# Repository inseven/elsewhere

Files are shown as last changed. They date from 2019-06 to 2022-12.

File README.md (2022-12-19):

# Elsewhere



Livestream picture frame

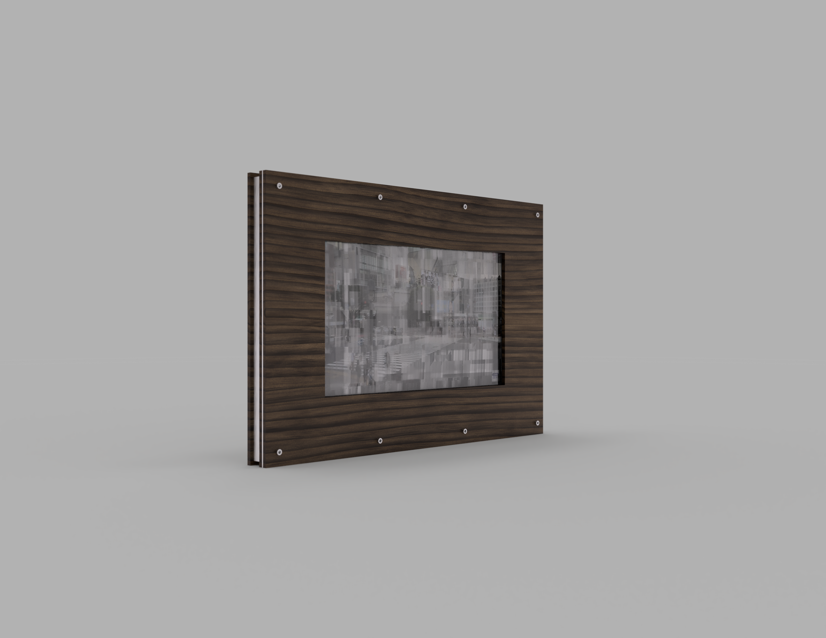
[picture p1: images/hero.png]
Render of the current Elsewhere design


## Parts

| **Part** | **Link** | Quantity | **Unit Price** | **Price** |
| --- | --- | --- | --- | --- |
| **Raspberry Pi Zero 2 W** | [Adafruit](https://www.adafruit.com/product/5291) | 1 | $15.00 | $15.00 |
| **Pimoroni HDMI 10" IPS LCD Screen Kit**  | [Adafruit](https://www.adafruit.com/product/4337) | 1 | $139.95 | $139.95 |
| HDMI Ribbon Cable, 30 cm | [Adafruit](https://www.adafruit.com/product/3562) | 1 | $2.75 | $2.75 |
| HDMI Plug Adapter | [Adafruit](https://www.adafruit.com/product/3548) | 1 | $6.50 | $6.50 |
| Mini HDMI Plug Adapter | [Adafruit](https://www.adafruit.com/product/3552) | 1 | $6.50 | $6.50 |
| **ATXRaspi R3** | [LowPowerLab](https://lowpowerlab.com/shop/product/91) | 1 | $17.95 | $17.95 |
| Jumper Wire | [LowPowerLab](https://lowpowerlab.com/shop/product/154) | 4 | $0.74 ($2.95 for 4) | $2.95 |
| D-Ring Picture Hanger, M4 | | 2 | | |
| USB-C Panel Mount | [eBay](https://www.ebay.com/itm/143134180140) | 1 | $6.29 | $6.29 |
| USB-C to Micro USB Adapter | [Amazon](https://www.amazon.com/gp/product/B07GH5KJH2/) | 1 | $6.99 | $6.99 |
| Micro USB Splitter Cable | [Amazon](https://www.amazon.com/gp/product/B017OPOG58/) | 1 | $6.79 | $6.79 |
| microSD Card, 32GB | [Amazon](https://www.amazon.com/SAMSUNG-Select-microSDXC-Adapter-MB-ME128HA/dp/B06XWN9Q99) | 1 | $7.99 | $7.99 |
| Female to Female Dupont Wire, 30cm | [Amazon](https://www.amazon.com/dp/B07GD1W1VL) | 6 | $0.08 ($8.99 for 120) | $0.48 |
| M3 Standoff, 10mm | [McMaster-Carr](https://www.mcmaster.com/94868A166/) | 8 | $1.24 | $9.92 |
| 4-40 Socket Head Screw, Low-Profile, 1/4" | [McMaster-Carr](https://www.mcmaster.com/93615A110/) | 2 | $1.55 (Pack of 10) | $3.10 |
| M3 Socket Head Screw, Low-Profile, 12mm | [McMaster-Carr](https://www.mcmaster.com/92855A313/) | 8 | $0.11 (Pack of 25) | $0.22 |
| M3 Socket Head Screw, Low-Profile, 6mm | [McMaster-Carr](https://www.mcmaster.com/92855A307/) | 8 | $0.30 (Pack of 25) | $0.60 |
| M2.5 Socket Head Screw, 6mm | [McMaster-Carr](https://www.mcmaster.com/91292A010/) | 18 | $0.06 ($6.00 for 100) | $1.08 |
| M2.5 Socket Head Screw, 4mm | [McMaster-Carr](https://www.mcmaster.com/91292A015/) | 18 | $0.30 ($7.43 for 25) | $5.40 |
| M2.5 Socket Head Screw, 10mm | [McMaster-Carr](https://www.mcmaster.com/91292A014/) | 2 | $0.07 ($6.54 for 100) | $0.14 |
| M2.5 Nut | [McMaster-Carr](https://www.mcmaster.com/91828A113/) | 2 | $0.08 ($7.18 for 100) | $0.16 |
| M2.5 Washer, 0.5mm | [McMaster-Carr](https://www.mcmaster.com/98689A111/) | 6 | $0.03 ($2.57 for 100) | $0.18 |
| M4 Socket Head Screw, Low-Profile, Partially Threaded, 10mm | [McMaster-Carr](https://www.mcmaster.com/96970A111/) | 2 | $1.48 | $2.96 |
| M4 Washer, 0.8mm | [McMaster-Carr](https://www.mcmaster.com/93475A230/) | 2 | $0.04 ($3.14 for 100) | $0.08 |
| M4 Locknut | [McMaster-Carr](https://www.mcmaster.com/93625A150/) | 2 | $0.08 ($7.67 for 100) | $0.16 |
| M2.5 Standoff, 6mm | [Digi-Key](https://www.digikey.com/en/products/detail/970060154/732-12827-ND/9488531) | 18 | $0.34 ($16.95 for 50) | $6.12 |
| **Laser-Cut Parts** | [Ponoko](https://ponoko.com) |  |  | $118.99 |
| **Controller Board** | [Oshpark](https://oshpark.com/shared_projects/Cnb1DUgJ) | 1 | $3.49 ($10.45 for 3) | $3.49 |
| Micro SD to Micro SD Extension Cable, 25cm | [AliExpress](https://www.aliexpress.com/item/4001154489373.html) | 1 | $3.00 | $3.00 |
| | | | | **$375.74** |

## Wiring

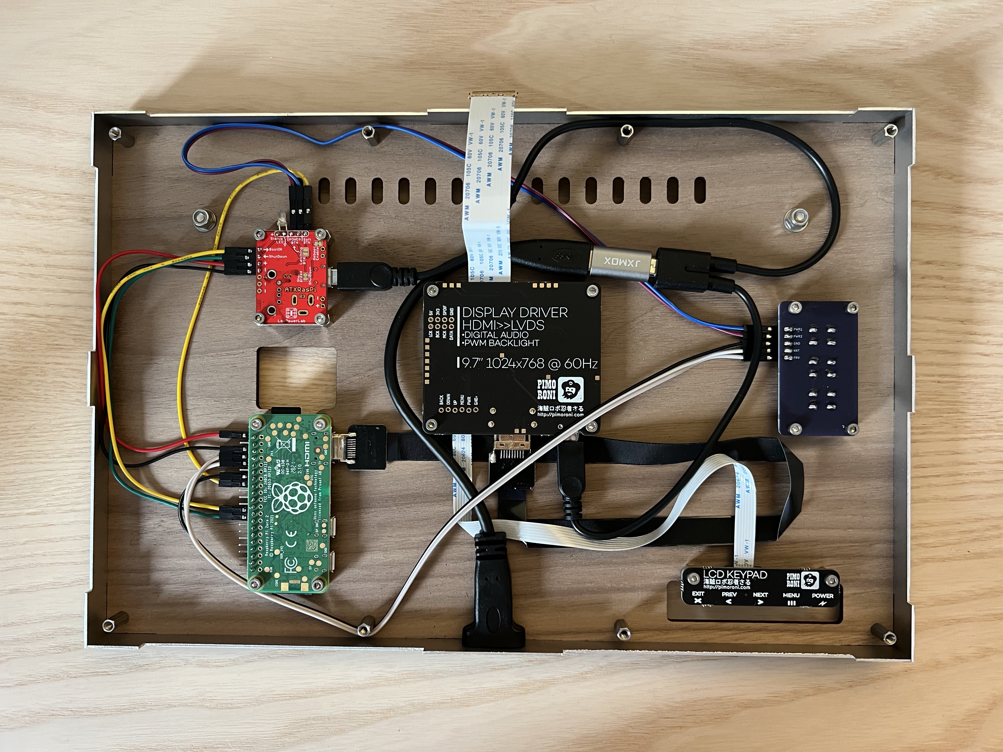
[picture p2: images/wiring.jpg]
Photograph of a recent version of Elsewhere showing the internal wiring


## Software Installation

1. Install Raspberry Pi OS Lite (Bullseye).

2. Add the package repository to `/etc/apt/sources.list`:

   ```bash
   deb [trusted=yes] http://packages.inseven.co.uk/raspbian/ ./
   ```

3. Update the `dtoverlay` property in `/boot/config.txt` to:

   ```ini
   dtoverlay=vc4-fkms-v3d
   ```

   (See https://forums.raspberrypi.com/viewtopic.php?t=324835.)
   
4. Add `fbcon=map:2 disable_splash=1 ` to `/boot/cmdline.txt`.

   These changes are as follows:

   - `fbcon=map:2` – Redirects the console during boot to ensure it doesn't appear on the HDMI display.
   - `disable_splash=1` – Disable the boot splash screen.

5. Disable the Serial Port and SPI:

   ```bash
   sudo raspi-config
   ```

   - Disable Serial Port
     - Interface Options
     - Serial Port
     - Login Shell: No
     - Serial Port Hardware: No
   - Disable SPI
     - Interface Options
     - SPI
     - Enabled: No

6. Reboot:

   ```bash
   sudo reboot
   ```

7. Update and upgrade Raspbian, and install Elsewhere:

   ```bash
   sudo apt update
   sudo apt upgrade --yes
   sudo apt install elsewhere --yes
   ```

8. Assuming everything has gone to plan, Elsewhere should now be running.

#### Unattended Upgrades

1. Enable all [unattended upgrades](https://wiki.debian.org/UnattendedUpgrades) by uncommenting the following lines in `/etc/apt/apt.conf.d/50unattended-upgrades`:

   ```
   Unattended-Upgrade::Origins-Pattern {
           // ...
           "origin=Debian,codename=${distro_codename}-updates";
           "origin=Debian,codename=${distro_codename}-proposed-updates";
           // ..
   }
   ```

2. Reboot:

   ```bash
   sudo reboot
   ```

## Troubleshooting

### Device takes too long to shutdown and ATXRaspi doesn't cut power

- Re-enable the console by removing `fbcon=map:2` from `/boot/cmdline.txt`.
- Check the the shutdown logs; are any services taking a long time to stop?

### Tailscale doesn't takes too long to stop

Customise the Tailscale service to shorten the shutdown timeout:

- Override the service:

  ```bash
  sudo systemctl edit tailscaled.service
  ```

- Add the following section:

  ```
  [Service]
  TimeoutSec=5
  ```

## Builds

Elsewhere is an iterative project, meaning I've put together a number of prototypes along the way. The most recent one still has the 4:3 aspect ratio, and has been happily showing us views from the ISS for the last few months.

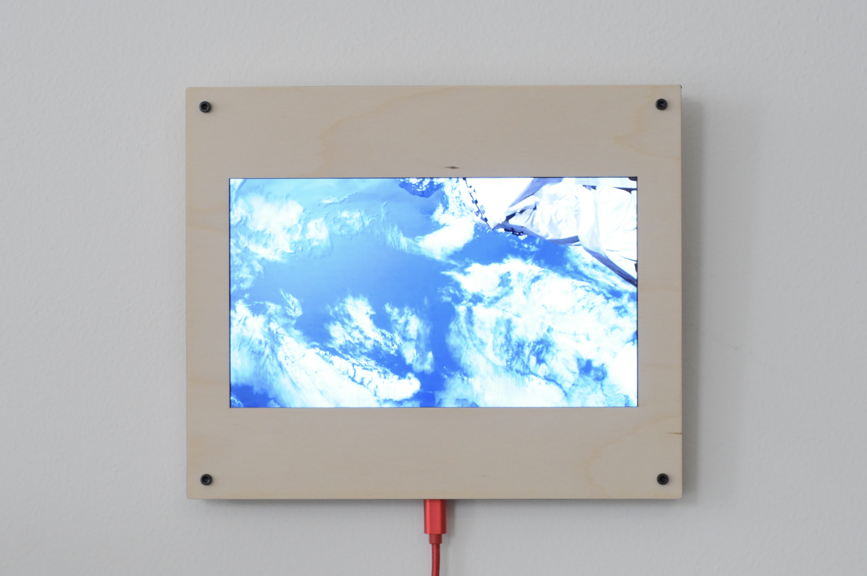
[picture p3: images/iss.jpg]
Elsewhere showing a livestream of Earth from the ISS


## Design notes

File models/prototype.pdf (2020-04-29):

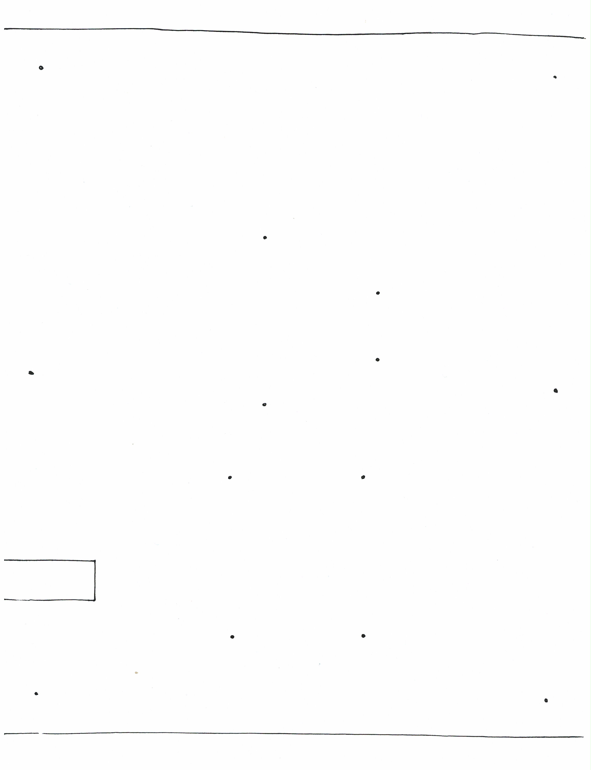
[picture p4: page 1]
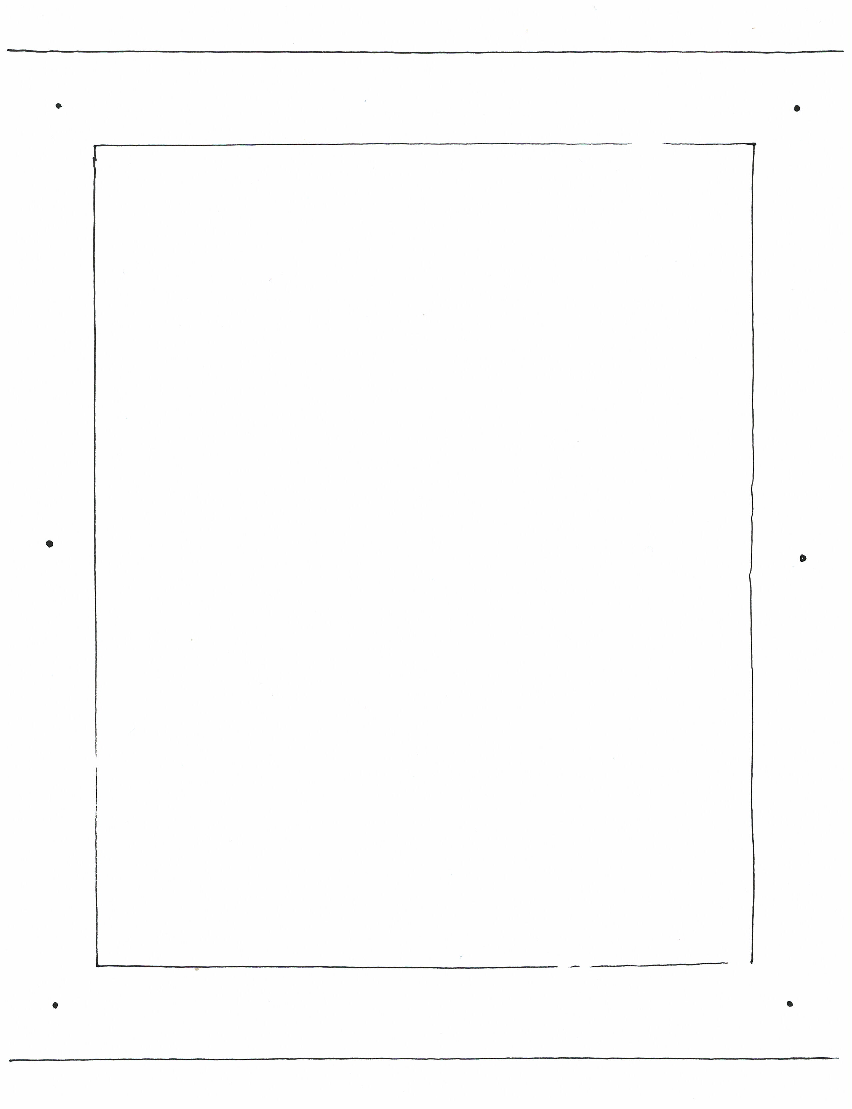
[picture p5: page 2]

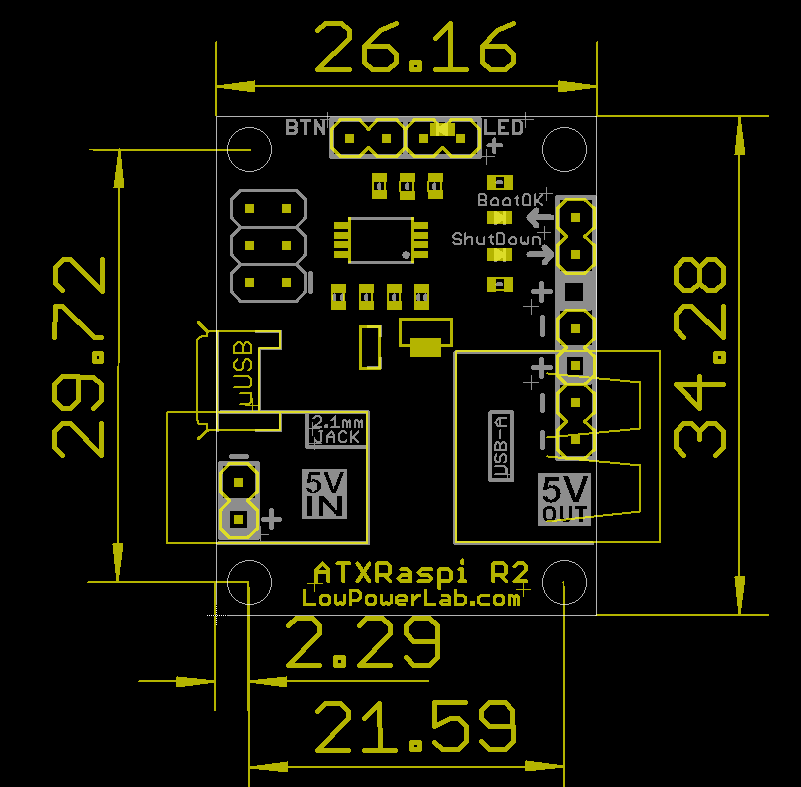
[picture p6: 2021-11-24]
schematics/ATXRaspi_R2_Outline_dimensions.png

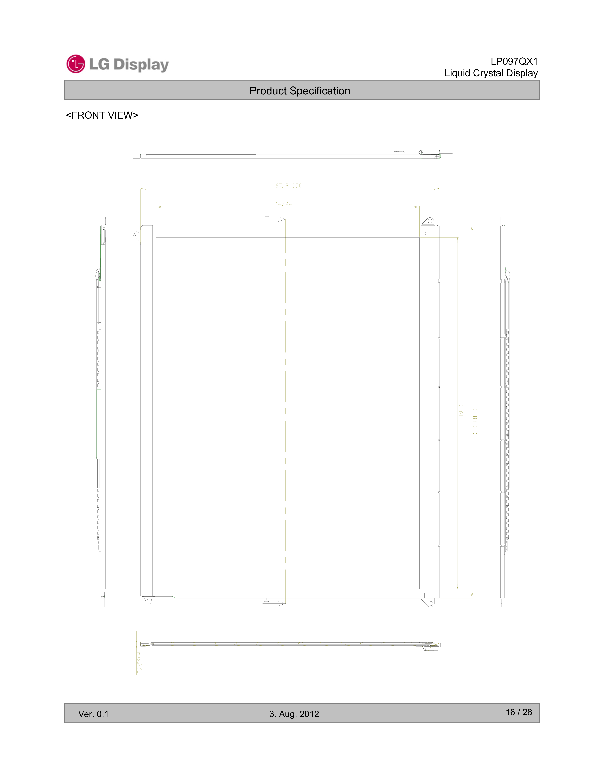
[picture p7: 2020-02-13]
schematics/LP097QX1-SPC1/front.png

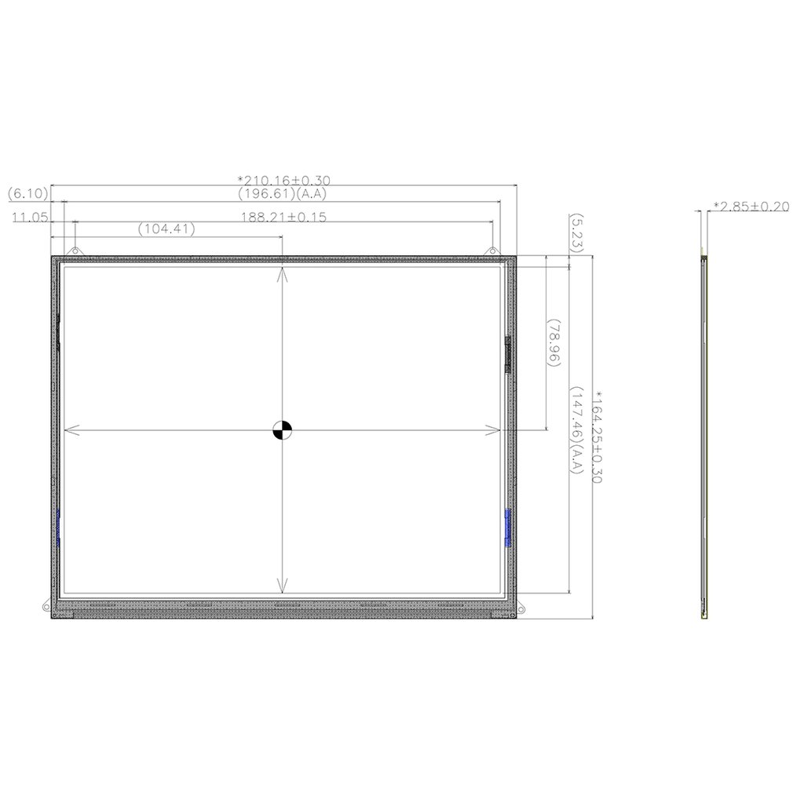
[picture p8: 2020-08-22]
schematics/10-inch-display-drawing_1024x1024.jpg

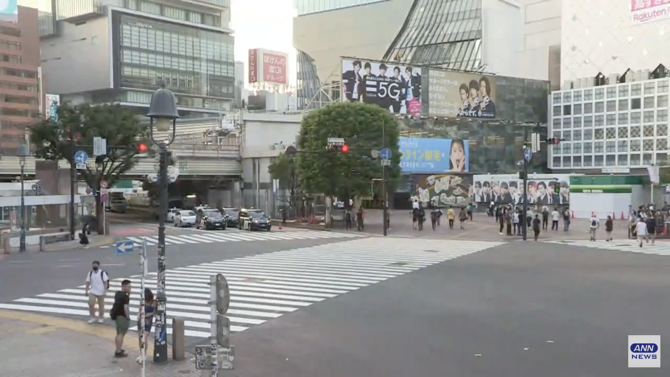
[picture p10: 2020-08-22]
models/placeholder.png

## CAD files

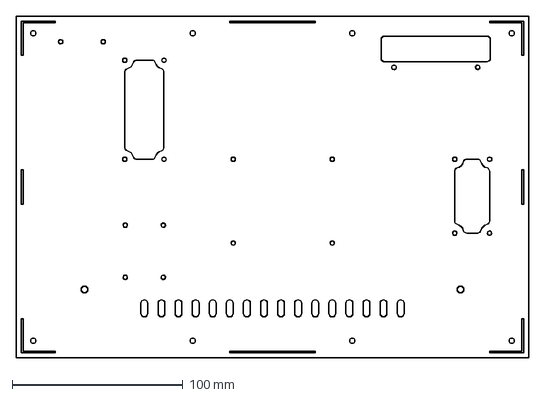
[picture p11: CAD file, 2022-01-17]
manufacture/v6/back.dxf
300.0 x 200.0 mm

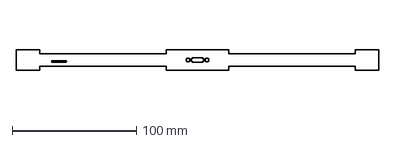
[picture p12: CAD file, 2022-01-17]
manufacture/v6/side-bottom.dxf
292.0 x 16.6 mm

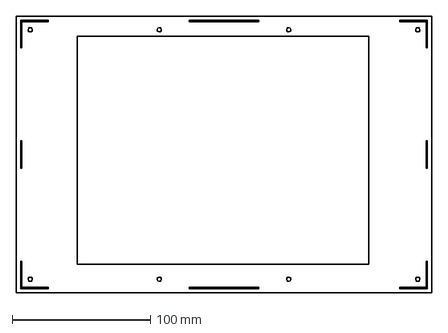
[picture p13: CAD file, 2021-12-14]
manufacture/v6/middle.dxf
300.0 x 200.0 mm

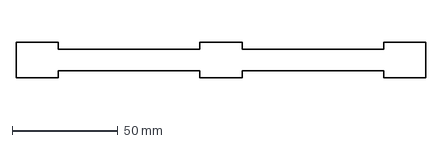
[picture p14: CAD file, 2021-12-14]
manufacture/v6/side-left.dxf
194.0 x 16.6 mm

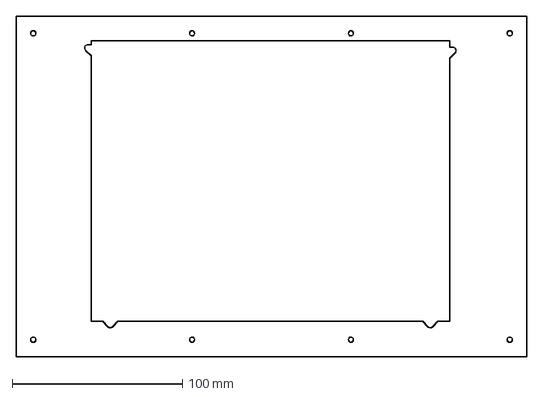
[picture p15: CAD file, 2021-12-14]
manufacture/v6/separator.dxf
300.0 x 200.0 mm

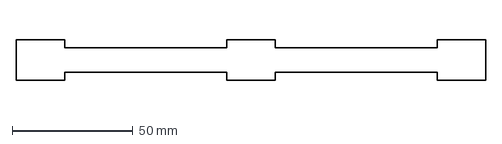
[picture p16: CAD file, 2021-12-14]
manufacture/v6/side-right.dxf
194.0 x 16.6 mm

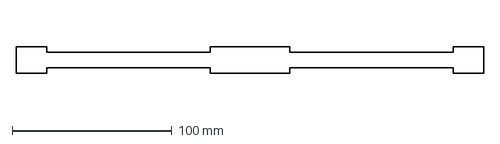
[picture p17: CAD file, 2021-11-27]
manufacture/v6/side-top.dxf
292.0 x 16.6 mm

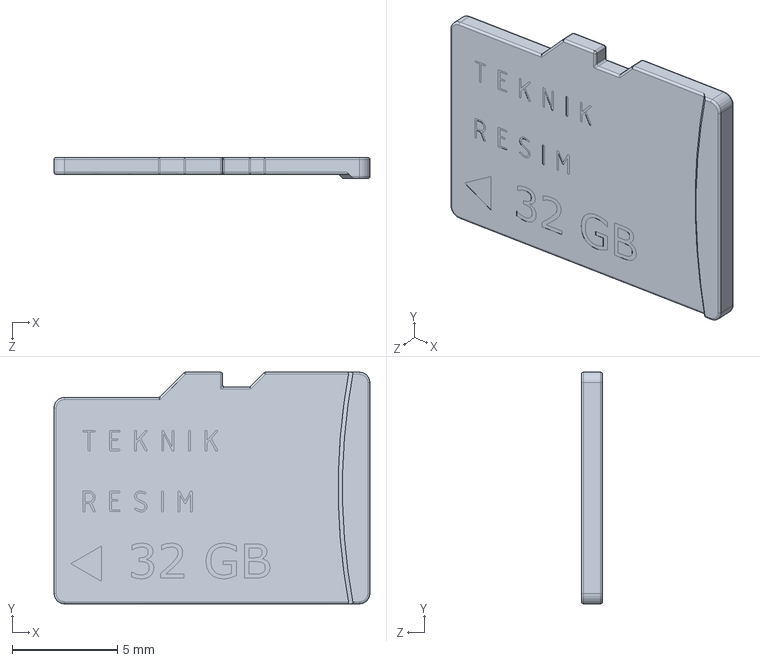
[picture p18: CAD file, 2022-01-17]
models/Micro SD Card.SLDPRT
15.0 x 11.0 x 1.00 mm

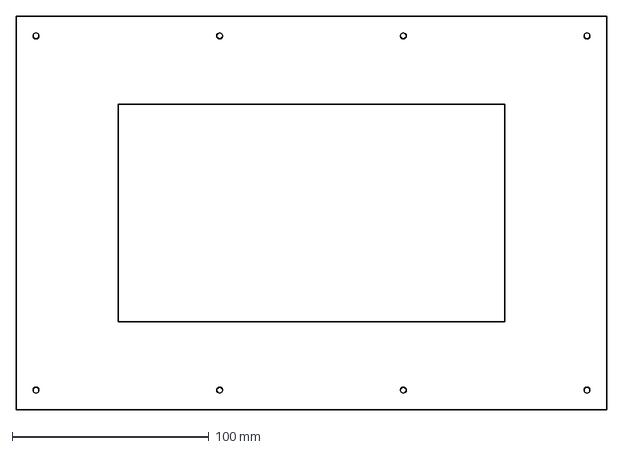
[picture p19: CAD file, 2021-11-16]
manufacture/v6/front.dxf
300.0 x 200.0 mm

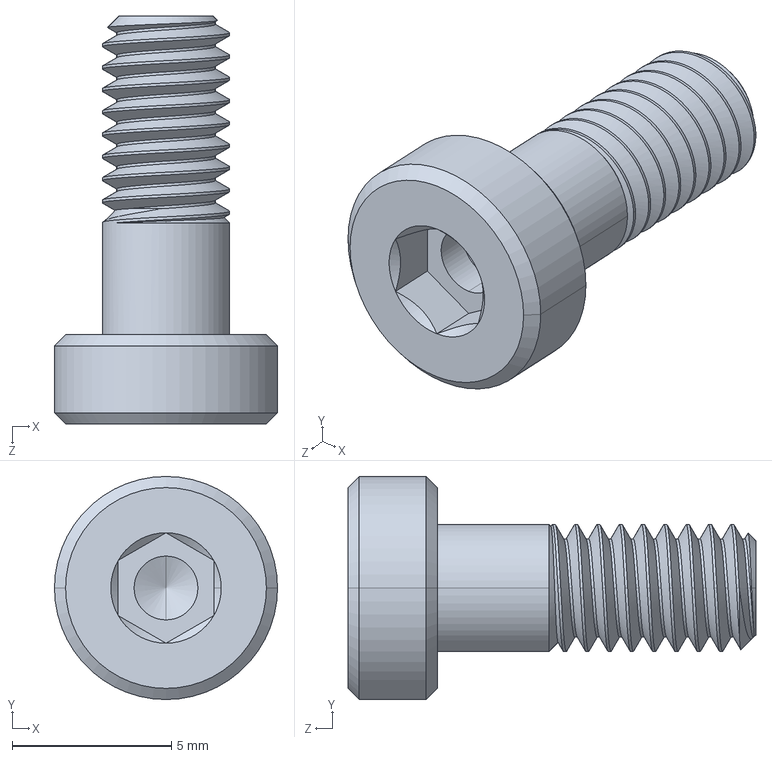
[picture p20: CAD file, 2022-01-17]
models/96970A111_18-8 Stainless Steel Low-Profile Socket Head Screw.STEP
7.00 x 7.00 x 12.8 mm

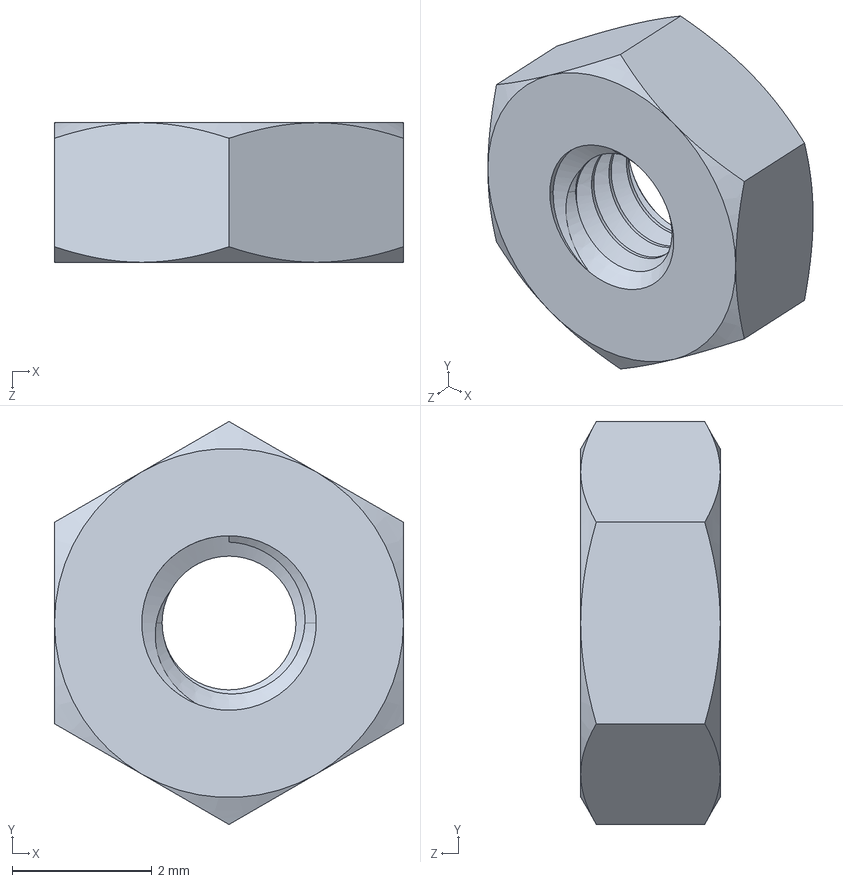
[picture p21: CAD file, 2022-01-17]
models/91828A113_18-8 Stainless Steel Hex Nut.STEP
5.00 x 5.77 x 2.00 mm

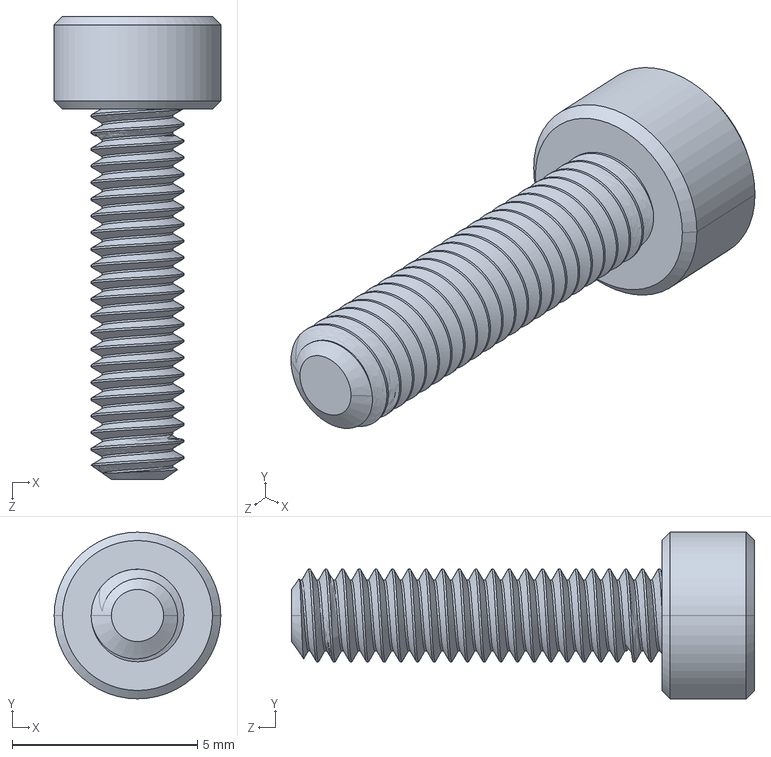
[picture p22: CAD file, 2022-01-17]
models/91292A014_18-8 Stainless Steel Socket Head Screw.STEP
4.50 x 4.50 x 12.5 mm

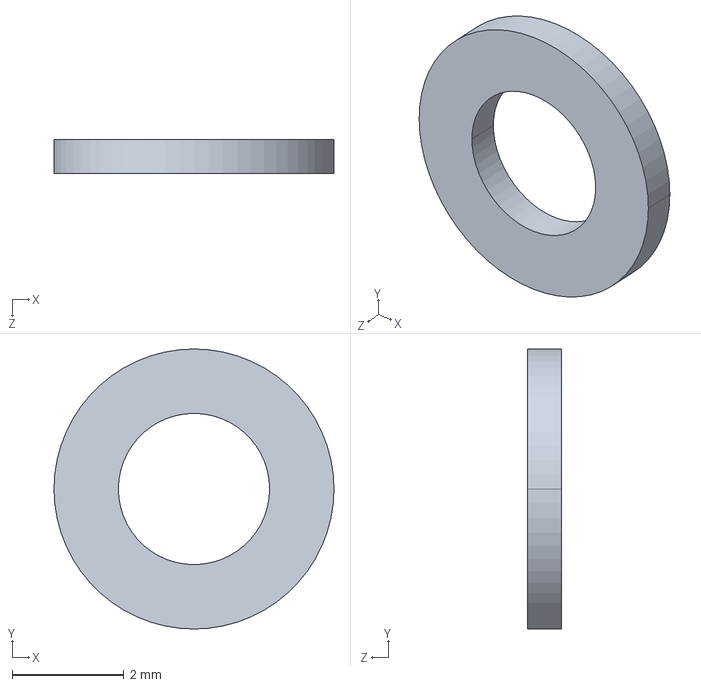
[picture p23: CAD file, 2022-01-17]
models/98689A111_General Purpose 18-8 Stainless Steel Washer.STEP
5.00 x 5.00 x 0.6 mm

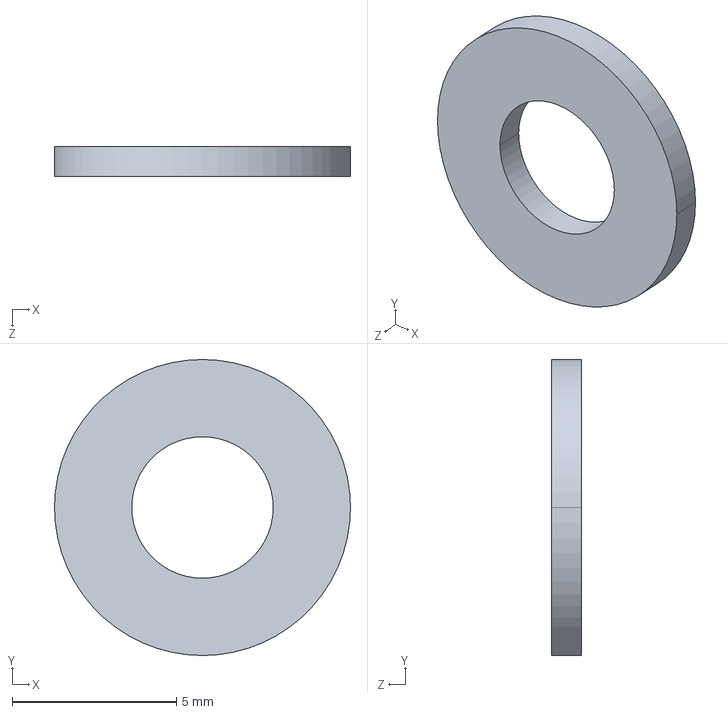
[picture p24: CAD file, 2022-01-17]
models/93475A230_18-8 Stainless Steel Washer.STEP
9.00 x 9.00 x 0.9 mm

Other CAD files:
models/93625A150_18-8 Stainless Steel Nylon-Insert Locknut.STEP
models/91292A010_18-8 Stainless Steel Socket Head Screw.SLDPRT
models/93615A110_18-8 Stainless Steel Low-Profile Socket Head Screw.SLDPRT
manufacture/v1/front.dxf
manufacture/v1/back.dxf
manufacture/v1/border.dxf
manufacture/v2/back.dxf
manufacture/v2/front.dxf
manufacture/v2/middle.dxf
manufacture/v2/separator.dxf
manufacture/v2/side-bottom.dxf
manufacture/v2/side-left.dxf
manufacture/v2/side-right.dxf
manufacture/v2/side-top.dxf
manufacture/v3/back.dxf
manufacture/v3/middle.dxf
manufacture/v3/side-bottom.dxf
manufacture/v3/side-left.dxf
manufacture/v3/side-right.dxf
manufacture/v3/side-top.dxf
manufacture/v4/back.dxf
manufacture/v4/middle.dxf
manufacture/v4/separator.dxf
manufacture/v4/side-bottom.dxf
manufacture/v4/side-left.dxf
manufacture/v4/side-right.dxf
models/PiZero.f3d

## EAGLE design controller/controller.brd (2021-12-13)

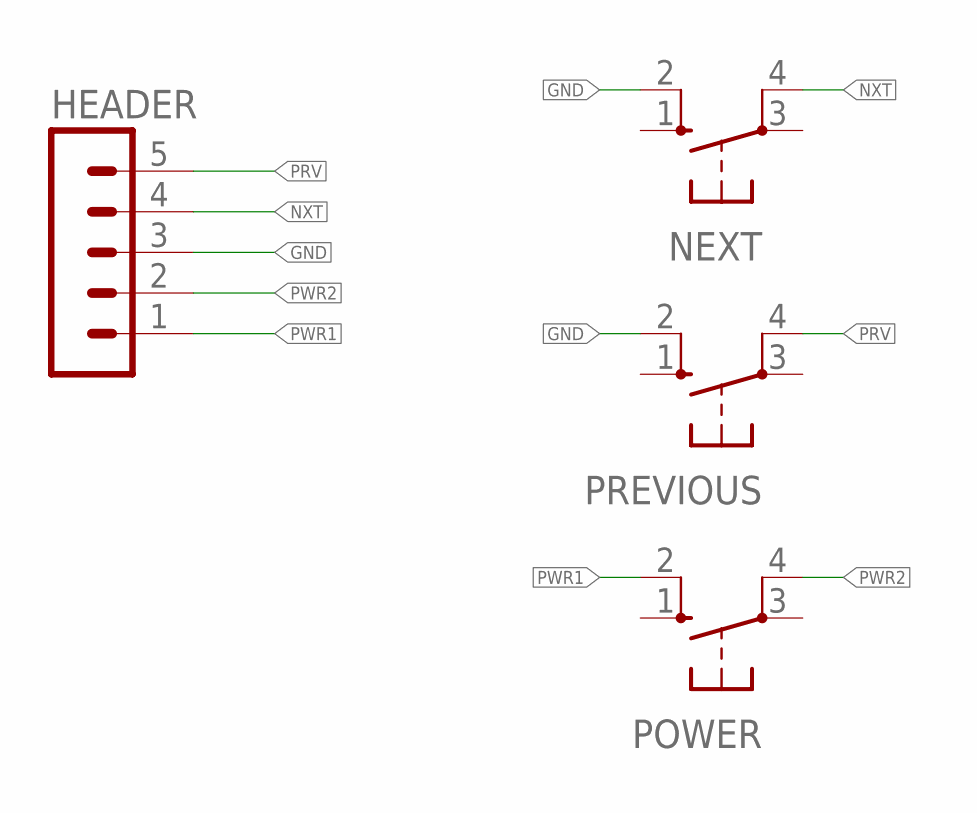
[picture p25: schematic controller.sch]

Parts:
HEADER: MA05-1
NEXT: 10-XX; B3F-10XX
POWER: 10-XX; B3F-10XX
PREVIOUS: 10-XX; B3F-10XX

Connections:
GND: HEADER.3, NEXT.2 (S1), PREVIOUS.2 (S1)
NXT: HEADER.4, NEXT.4 (P1)
PRV: HEADER.5, PREVIOUS.4 (P1)
PWR1: HEADER.1, POWER.2 (S1)
PWR2: HEADER.2, POWER.4 (P1)

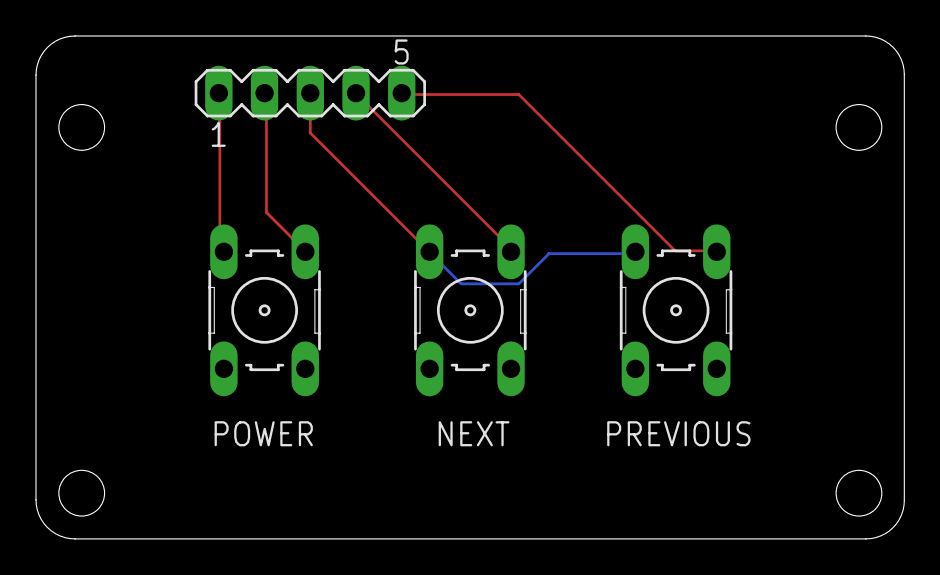
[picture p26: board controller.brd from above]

Board: 2 copper layers, 48.2 x 27.9 mm, 4 parts (0 on the bottom side), 5 nets.

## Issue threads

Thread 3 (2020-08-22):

Add vents to the rear of the device

jbmorley, 2020-08-22:

jbmorley, 2020-09-15:
Fixed.

Closed 2020-09-15.

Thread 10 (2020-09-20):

Add a cutout to make it easy to manipulate the display ribbon cable

jbmorley, 2020-09-20:
Adding a cutout to the rear of the case to make it easier to manipulate the ribbon cable once the display controller board is fixed in place should make assembly much easier.

jbmorley, 2021-11-13:
This doesn't actually seem necessary at this point.

Closed 2021-11-13.

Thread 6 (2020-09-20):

Increase the USB-C port aperture

jbmorley, 2020-09-20:
The hole for the USB port isn't quite large enough and needs a little more clearance.

jbmorley, 2021-11-13:
Done.

Closed 2021-11-13.

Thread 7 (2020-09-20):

Add a cutout for the Raspberry Pi SD card

jbmorley, 2020-09-20:
It'd be great to be able to get access to the SD card with the case fully assembled.

jbmorley, 2021-11-13:
Done.

Closed 2021-11-13.

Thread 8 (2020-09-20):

Consider making the case aspect ratio match the screen aspect ratio

jbmorley, 2020-09-20:
I think this would make it more visually balanced.

jbmorley, 2021-11-13:
16:9 didn't feel quite right, but 4:3 seems to work pretty well.

Closed 2021-11-13.

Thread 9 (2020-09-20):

Flip the Raspberry Pi over in the design

jbmorley, 2020-09-20:
Turning the Raspberry Pi over so the chips face outwards will make the SD card face the rear opening and make it much easier to access. It will also mean that the processor (and any heat sync) are fully exposed to the outside of the case which should help keep the temperature down.

jbmorley, 2021-11-13:
Done.

Closed 2021-11-13.

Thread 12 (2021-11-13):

Double check there's sufficient clearance for the display

jbmorley, 2021-11-13:
It looks like the screen may be bowing a little in the current implementation.

jbmorley, 2021-11-13:
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

jbmorley, 2021-11-13:
👌🏻

Closed 2021-11-13.

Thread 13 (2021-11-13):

Order parts for the updated devices

jbmorley, 2021-11-13:
- [x] 8 x 10mm standoffs
- [x] 8 x 12mm M3 hex bolts
- [x] 8 x 6mm M3 hex bolts
- [x] M2.5 bolts for the PCB mounting
- [x] M2.5 standoffs for the PCB mounting
- [x] 2 x M4 bolts for the picture frame hooks
- [x] 2 x M4 nuts for the picture frame hooks (locking nuts?)
- [x] 2 x M4 washers for the picture frame hooks

jbmorley, 2021-11-13:
Don't forget the M2.5 mountings for the PCBs.

jbmorley, 2021-11-13:
Bolts for mounting the picture frame hangers.

jbmorley, 2021-11-14:
- Second display (https://www.adafruit.com/product/4337)
- HDMI cables
- USB-C cable

jbmorley, 2021-11-26:
- [ ] Wood oil
- [ ] Sandpaper

jbmorley, 2021-12-27:
Done.

Closed 2021-12-27.

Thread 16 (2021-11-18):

Consider adding reinforcing bolts on the left and right sides

jbmorley, 2021-11-18:

jbmorley, 2021-11-26:
Closing as won't fix; we can re-raise this if there are actually issues.

Closed 2021-11-26.

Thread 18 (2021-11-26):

Custom PCB for controlling the device and display

jbmorley, 2021-11-26:
it would be great to be able to unify the display control board and the device controls (power, channel switching, etc) with a common control board which is designed with right-angle switches that can be pressed from the side of the device.

jbmorley, 2021-11-26:
Since this doesn't actually need to do anything more complex than provide a common mounting point for the switches, it might be possible to use some breadboard.

jbmorley, 2021-12-27:
Done.

Closed 2021-12-27.

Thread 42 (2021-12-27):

Create an Ansible script to set up a new Raspberry Pi

jbmorley, 2021-12-27:

jbmorley, 2021-12-31:
Closing as won't fix.

Closed 2021-12-31.

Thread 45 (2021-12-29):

Stop showing the version when the device has booted

jbmorley, 2021-12-29:

jbmorley, 2022-01-02:
I've made this change, but now it doesn't appear to be showing the splash at all.

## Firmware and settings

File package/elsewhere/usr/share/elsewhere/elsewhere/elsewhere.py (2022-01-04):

#!/usr/bin/env python3

# Copyright (c) 2018-2021 Jason Morley
#
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
import argparse
import atexit
import logging
import os
import re
import signal
import subprocess
import sys
import tempfile
import threading
import time
import urllib.request

import RPi.GPIO as GPIO
import gpiozero
import requests

from flask import Flask, escape, request, jsonify, send_from_directory

ROOT_DIRECTORY = os.path.dirname(os.path.abspath(__file__))
ELSEWHERE_DIRECTORY = "/usr/share/elsewhere"
SPLASH_DIRECTORY = os.path.join(ELSEWHERE_DIRECTORY, "splash")
IMAGES_DIRECTORY = os.path.join(SPLASH_DIRECTORY, "images")
SPLASH_IMAGE_PATH = os.path.join(IMAGES_DIRECTORY, "elsewhere.png")
SHUTTING_DOWN_IMAGE_PATH = os.path.join(IMAGES_DIRECTORY, "shutting-down.png")
FIM_SCRIPT_PATH = os.path.join(SPLASH_DIRECTORY, "script.txt")
FONT_PATH = os.path.join(ELSEWHERE_DIRECTORY, "fonts/Inter/static/Inter-Thin.ttf")

logging.basicConfig(level=logging.INFO, format="[%(asctime)s] [%(process)d] [%(levelname)s] %(message)s", datefmt='%Y-%m-%d %H:%M:%S %z')


def livestreamer(url):
    return subprocess.Popen(["streamlink", "--player", "cvlc --fullscreen --no-video-title-show", url, "best"])


app = Flask(__name__)


@app.after_request
def add_header(r):
    """
    Add headers to both force latest IE rendering engine or Chrome Frame,
    and also to cache the rendered page for 10 minutes.
    """
    r.headers["Cache-Control"] = "no-cache, no-store, must-revalidate"
    r.headers["Pragma"] = "no-cache"
    r.headers["Expires"] = "0"
    r.headers['Cache-Control'] = 'public, max-age=0'
    return r


@app.route('/')
def hello():
    return send_from_directory(ROOT_DIRECTORY, 'index.html')


class Server(threading.Thread):

    def __init__(self, player, *args, **kwargs):
        super().__init__(*args, **kwargs)
        self.player = player
        def next():
            self.player.next()
            return jsonify({'url': self.player.url})
        def previous():
            self.player.previous()
            return jsonify({'url': self.player.url})
        def shutdown_action():
            shutdown()
            return jsonify({})
        def reboot_action():
            reboot()
            return jsonify({})
        app.add_url_rule('/api/v1/next', 'next', next)
        app.add_url_rule('/api/v1/previous', 'previous', previous)
        app.add_url_rule('/api/v1/shutdown', 'shutdown', shutdown_action)
        app.add_url_rule('/api/v1/reboot', 'reboot', reboot_action)

    def run(self):
        app.run(host='0.0.0.0')


class Streamer(threading.Thread):

    def __init__(self, url, *args, **kwargs):
        super().__init__(*args, **kwargs)
        self.url = url
        self.lock = threading.Lock()
        self._should_stop = False
        self.process = None

    def run(self):
        while True:
            process = None
            with self.lock:
                if self._should_stop:
                    return
                else:
                    # TODO: Rename to streamlink
                    process = livestreamer(self.url)
                    self.process = process
            process.wait()

    def stop(self):
        with self.lock:
            self._should_stop = True
            self.process.send_signal(signal.SIGINT)
            # self.process.kill()
        self.join()


def show_image(path):
    subprocess.check_call(["/usr/bin/fim", "--quiet", path, "--execute-script", FIM_SCRIPT_PATH])


def show_title(title):
    with tempfile.TemporaryDirectory() as directory:
        logging.info("Setting title to '%s'...", title)
        image_path = os.path.join(directory, "image.png")
        subprocess.check_call(["/usr/bin/convert",
                               "-background", "black",
                               "-fill", "white",
                               "-font", FONT_PATH,
                               "-size", "1024x768",
                               "-pointsize", "48",
                               "-gravity", "center",
                               "label:%s" % (title, ),
                               image_path])
        show_image(image_path)


class Player(object):

    def __init__(self, urls):
        self.streamer = None
        self.urls = urls
        self.index = 0

    def play(self):
        if self.streamer is not None:
            self.streamer.stop()
        url = self.url
        logging.info(f"Playing {url}...")
        title = self.title
        show_title(title)

        self.streamer = Streamer(url=url)
        self.streamer.setDaemon(True)
        self.streamer.start()

    def next(self):
        self.index = (self.index + 1) % len(self.urls)
        self.play()

    def previous(self):
        self.index = (self.index - 1) % len(self.urls)
        self.play()

    def cleanup(self):
        self.streamer.stop()

    @property
    def url(self):
        return self.urls[self.index][0]

    @property
    def title(self):
        details = self.urls[self.index]
        if len(details) > 1:
            return details[1]
        return ""


def setup_buttons(commands):
    buttons = []
    for pin, command in commands.items():
        button = gpiozero.Button(pin)
        button.when_pressed = command
        buttons.append(button)
    return buttons


def shutdown():
    # Signal the ATXRaspi (short button press).
    soft_button = 23
    GPIO.setup(soft_button, GPIO.OUT)
    GPIO.output(soft_button, GPIO.HIGH)
    time.sleep(0.4)
    GPIO.output(soft_button, GPIO.LOW)


def reboot():
    # Signal the ATXRaspi (long button press).
    soft_button = 23
    GPIO.setup(soft_button, GPIO.OUT)
    GPIO.output(soft_button, GPIO.HIGH)
    time.sleep(4.1)
    GPIO.output(soft_button, GPIO.LOW)


def main():
    parser = argparse.ArgumentParser(description="Livestream picture frame software.")
    parser.add_argument("streams", help="URL containing new-line separated livestream URLs")
    parser.add_argument("--no-gpio", action="store_true", default=False, help="disable GPIO for channel controls")
    options = parser.parse_args()

    show_image(SPLASH_IMAGE_PATH)
    GPIO.setmode(GPIO.BCM)

    content = None
    if os.path.exists(options.streams):
        with open(options.streams, "r") as fh:
            content = fh.read()
    else:
        response = requests.get(options.streams)
        content = response.text
    lines = [re.sub(r"(#.+)", "", line.strip()) for line in content.split("\n")]
    urls = [line.split(" ", 1) for line in lines if line]
    player = Player(urls=urls)
    if not options.no_gpio:
        logging.info("Setting up GPIO buttons...")
        buttons = setup_buttons({
            14: player.previous,
            15: player.next,
        })
    else:
        logging.info("Skipping GPIO button setup...")

    logging.info("Starting server...")
    server = Server(player=player)
    server.setDaemon(True)
    server.start()

    def kill(*args):
        player.cleanup()
        show_image(SHUTTING_DOWN_IMAGE_PATH)
        exit()

    signal.signal(signal.SIGINT, kill)
    signal.signal(signal.SIGTERM, kill)

    player.play()
    signal.pause()


if __name__ == "__main__":
    main()

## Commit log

2020-02-13 Move the schematics around, and add an export of just the front schematic.
2020-02-13 Add the SVG of the display schematics.
2020-04-29 Add prototype sketch.
2020-06-27 Experimental support for respawning the player if it crashes.
    [elsewhere.py]
2020-06-28 Support changing channels with the threaded player.
2020-06-30 Add CAD model.
    [back.dxf, front.dxf]
2020-07-08 Replace the Tokyo stream.
    [elsewhere.py]
2020-07-10 Update the CAD files.
    [back.dxf, border.dxf]
2020-08-18 Support skipping GPIO for control buttons and use the Pimoroni Inky pHAT as a display for stream titles.
    [elsewhere.py]
2020-08-22 Add panel schematic
2020-08-22 Add a model
    [PiZero.f3d]
2020-08-24 Add Raspberry Pi Zero schematic.
2020-08-25 Add the new manufacture exports.
    [back.dxf, border.dxf, front.dxf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]
2020-08-25 Move the prototype sketches into the models folder.
2020-08-25 Update the BOM
2020-08-25 Add the HDMI cable
2020-08-25 Add a web server for controlling the device.
2020-09-10 Add the first-cut service files.
2020-09-10 Lowercase buttons.
2021-11-13 Add updated cut files with wider aspect ratio and many improvements
    - control mounts
    - improved hook mounting
    - larger USB-C cutout
    - SD card access
    - cleaner sides (fewer vents)
    - hidden joint between side panels
    [back.dxf, front.dxf, middle.dxf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]
2021-11-16 Don't round the corners.
    [back.dxf, front.dxf, middle.dxf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]
2021-11-17 Add the USB-C mounting screws.
2021-11-17 More screws, and total price.
2021-11-17 Add screw.
    [93615A110_18-8 Stainless Steel Low-Profile Socket Head Screw.SLDPRT]
2021-11-19 Add the microSD card to the BOM.
2021-11-24 Add the ATXRaspi schematic from the website.
2021-11-26 Add PCB mounting standoffs and screws.
2021-11-27 Brief comment about the most recent prototype.
2021-11-27 Add the v4 manufacture DXF files.
    [back.dxf, front.dxf, middle.dxf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]
2021-11-27 Add an updated bottom side for the v3 build with a cutout for the power microswitch
    [side-bottom.dxf]
2021-11-27 Add another stnadard part.
    [91292A010_18-8 Stainless Steel Socket Head Screw.SLDPRT]
2021-11-27 Add the laser cut parts to the BoM.
2021-12-06 Remove the prototype eInk script.
2021-12-13 Add a small PCB with buttons for power and controlling the channels
    [controller.brd, controller.sch]
2021-12-13 Link the controller PCB with Fusion.
    [controller.brd]
2021-12-14 Add the latest manufacture files.
    [back.dxf, front.dxf, middle.dxf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]
2021-12-18 Update the PCB mounting standoffs and screws.
2021-12-27 fix: Support ATXRaspi power manaagement and add a splash screen
    [elsewhere.py]
2021-12-27 fix: Use title case for the application name in the web frontend
2021-12-27 fix: Include the Python dependencies in the debian package
    [elsewhere.py]
2021-12-29 fix: Only show the version number during startup
    [elsewhere.py]
2022-01-16 Update for the Raspberry Pi Zero 2 W.
2022-01-17 Add the Elsewhere controller board to the BoM
2022-01-17 Add the Micro SD extension cable to the BoM
2022-01-17 Add the v6 DXF files
    [back.dxf, front.dxf, middle.dxf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]
2022-01-17 Add the M4 mounting hardware from McMaster-Carr
2022-01-17 Add the SD card mounting hardware and the wires to the BoM
2022-01-17 Add models.
    [91292A014_18-8 Stainless Steel Socket Head Screw.STEP, 91828A113_18-8 Stainless Steel Hex Nut.STEP, 93475A230_18-8 Stainless Steel Washer.STEP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]
2022-03-24 docs: Add a photo showing the internal inter-board wiring
